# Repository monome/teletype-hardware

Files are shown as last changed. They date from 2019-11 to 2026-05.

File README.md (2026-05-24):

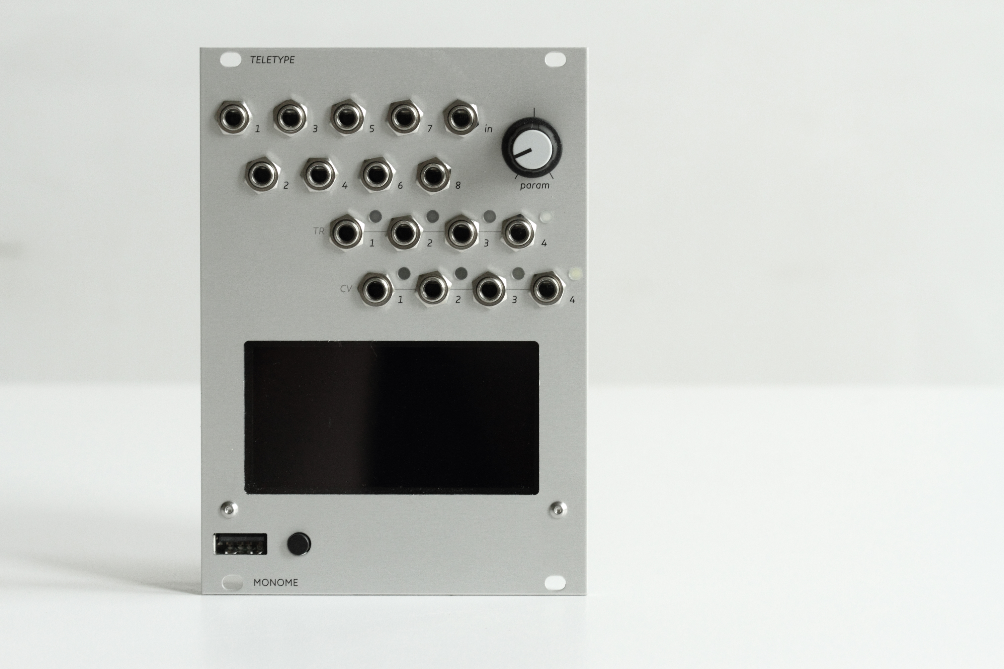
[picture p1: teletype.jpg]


# teletype hardware

eurorack module by https://monome.org

created by brian crabtree (bcrabtree@monome.org)

all circuits in eagle. can be imported to kicad.

firmware: https://github.com/monome/teletype

## BOM

- components: see ods
- octopart: https://octopart.com/bom-tool/cjqXTx5c
- mechanical (screws and spacers)
  - mcmaster: 91780A023, 91772A077, 91772A073

## license

[cc-by-sa-3.0](https://creativecommons.org/licenses/by-sa/4.0/)

commerical use: send $10 per unit produced to tehn@nnnnnnnn.co via paypal

do not use the name "monome" or "teletype" in derivative works.

## warranty and support

we can provide neither

## thank you

everyone who helped this module live

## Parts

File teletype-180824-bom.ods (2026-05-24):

250 | Qty | Value | Package | Parts | Part Number
 | --- | TOP SMD
5000 | 20 | 100n | C0402 | C1, C3, C7, C18, C21, C22, C23, C32,C26, C27, C29, C30, C31, C41, C42, C46, C47, C50, C56, C59 | CL05B104KO5NNNC
2250 | 9 | 1n | C0402 | C34, C35, C36, C37, C38, C39, C43, C57, C58 | GRM155R71H102KA01D
1000 | 4 | 2.7n | C0402 | C8, C13, C14, C15 | GRM155R71H272KA01D
500 | 2 | 22p | C0402 | C19, C20 | C0402C220J4GACTU
2250 | 9 | 33n | C0402 | C10, C12, C16, C17, C33, C45, C52, C53, C54 | CL05B333KA5NNNC
250 | 1 | 470p | C0402 | C11 | UMK105B7471KV-F
750 | 3 | 2.2u | C0603 | C9, C48, C55 | 490-10731-2-ND
500 | 2 | 4.7u | C0603 | C49, C51 | CL10A475KO8NNNC
1750 | 7 | 10u | C1206/T | C4, C6, C24, C25, C28, C44, C60 | 1276-1075-2-ND
250 | 1 | 4.7u | C1206/T | C5 | F931C475KAA
250 | 1 | 220u | C7343-43 | C2 | 478-3284-2-ND
1000 | 4 | OR | CHIP-LED0805 | LED1, LED2, LED3, LED4 | APT1608SYCK
1000 | 4 | W | CHIP-LED0805 | LED5, LED6, LED7, LED8 | LTW-C191TS5
500 | 2 | PTC-F0805-15V | F1206 | PF1, PF2 | 507-1805-2-ND
250 | 1 | 12mhz | HC49UP | Y1 | ECS-120-18-5PX-TR
250 | 1 | 47k | MNR35 | RN1 | MNR35473CT-ND
1000 | 4 | 0 | R0402 | R41, R42, R45, R48 | RC0402JR-070RL
500 | 2 | 39 | R0402 | R43, R44
4000 | 16 | 10k | R0402 | R4, R6, R7, R9, R11, R12, R13, R18, R22, R26, R28, R31, R33, R35, R39, R40 | RC0402FR-0710KL
2000 | 8 | 1k | R0402 | R3, R8, R10, R14, R17, R21, R29, R51 | 311-1.0KJRTR-ND
2000 | 8 | 20k | R0402 | R37, R38, R46, R47, R52, R53, R66, R67 | 311-20.0KLRTR-ND
500 | 2 | 2k | R0402 | R5, R16 | RC0402FR-072KL
3250 | 13 | 30k | R0402 | R15, R19, R23, R24, R25, R27, R30, R32, R34, R36, R56, R58, R60 | 311-30.0KLRTR-ND
250 | 1 | 31k6 | R0402 | R20 | YAG3115TR-ND
500 | 2 | 47k | R0402 | R1, R2 | RC0402FR-0747KL
250 | 1 | TPS2021 | SO08 | U1 | TPS2021DR
250 | 1 | TL074 | SO14 | IC1 | 296-1283-6-nd
250 | 1 | OPA4171 | SO14 | IC4 | 296-29037-1-ND
250 | 1 | ADP3339 | SOT223 | U40 | ADP3339AKCZ-3.3-R7
2500 | 10 | BAS70-04 | SOT23 | D2, D3, D4, D5, D6, D7, D8, D9, U6, U44 | BAS70-04TPMSCT-ND
250 | 1 | OKI-78SR | TO220V | IC2 | 811-2692-ND
250 | 1 | AT32UC3B064/0128/0256 | TQFP64-10X10 | U2 | AT32UC3B0512-A2UT
500 | 2 | AD5687R | TSSOP16 | U3, U4 | AD5687RBRUZ-ND
250 | 1 | AD7923 | TSSOP16 | U7 | AD7923BRUZ
 | --- | TH
250 | 1 | 10k | ALPS_POT_VERTICAL_PS | P1
250 | 1 | 1x20xFEM | 1x20 | U$1 | 1212-1105-ND
250 | 1 | USB-VERT | MOLEX-USB | USB | WM8672-ND
4250 | 17 | WQP-PJ301M-12_JACK | WQP-PJ301M-12_JACK | J1, J2, J3, J4, J5, J6, J7, J8, J9, J10, J11, J12, J13, J14, J15, J16, J17
250 | 1 |  | SWITCH-OMRON_B3F-10XX | POP | 450-1655-ND
500 | 2 |  | 2X03 | JP1, JP2 | 609-3218-ND
250 | 1 | 2510- | 2x10-SHROUDED | X1 | ED1543-ND
250 | 1 | DNP | PANASONIC-EVQ | SW40
250 | 1 | DNP | ISP-ROW | J40
250 | 1 | OLED-HEADER | 1x20xMALE |  | 1212-1149-ND

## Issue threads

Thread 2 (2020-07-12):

R22 and C22 seems to be marked switched on the pcb?

KitKatAndy, 2020-07-12:

tehn, 2020-07-15:
are you sure C22 and R22 are the correct parts you're talking about? just checked the eagle files and those parts numbers don't exist... something may be confused

tehn, 2020-07-15:
edit, just kidding, i was checking the norns shield files, ahh

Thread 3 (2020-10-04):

10k and 1k Resistors on BOM

in-fm, 2020-10-04:
The 10k and 1k resistor part numbers are switched and link to the wrong products
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

tehn, 2020-10-04:
fixed

Closed 2020-10-04.

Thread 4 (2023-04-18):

Add gerbers to repository

drbloop, 2023-04-18:
I would like to fabricate some PCBs but I haven't been able to get Eagle to work properly on my machine to convert the PCB `.brd` file to gerber files that are required for PCB fab services. Is it possible to do this conversion on your end and upload the gerber zip files to this repository? I think this will help others out too, by removing the need to do a conversion step.

Example from a Teletype expansion board - https://github.com/bpcmusic/telex/tree/master/hardware/TELEXi/board/gerbers

tehn, 2023-04-18:
We've posted these files for educational purposes, not as an online store.

Closed 2023-04-18.

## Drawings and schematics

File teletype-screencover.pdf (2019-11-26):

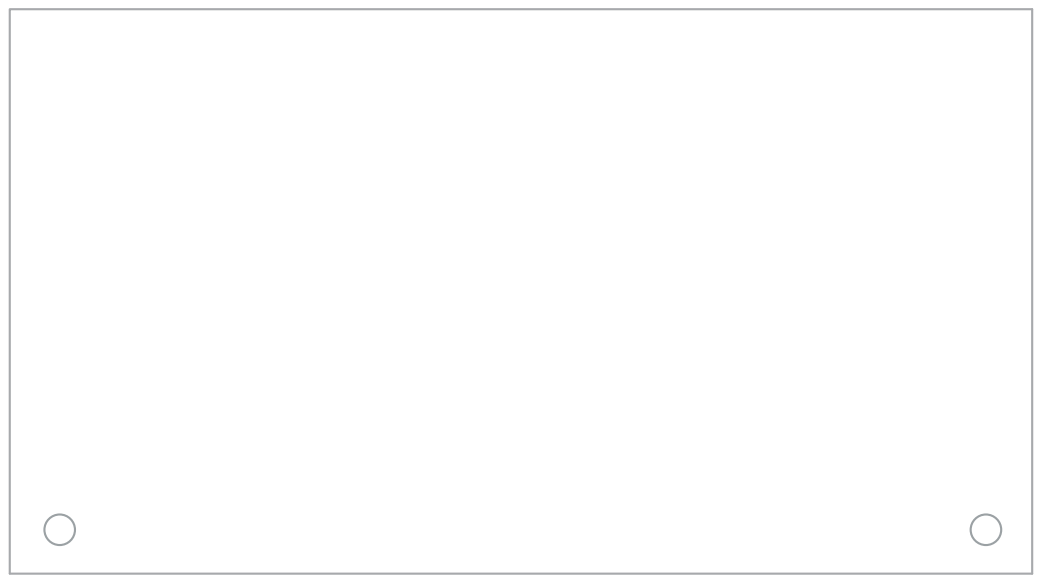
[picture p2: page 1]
TELETYPE; MONOME; param

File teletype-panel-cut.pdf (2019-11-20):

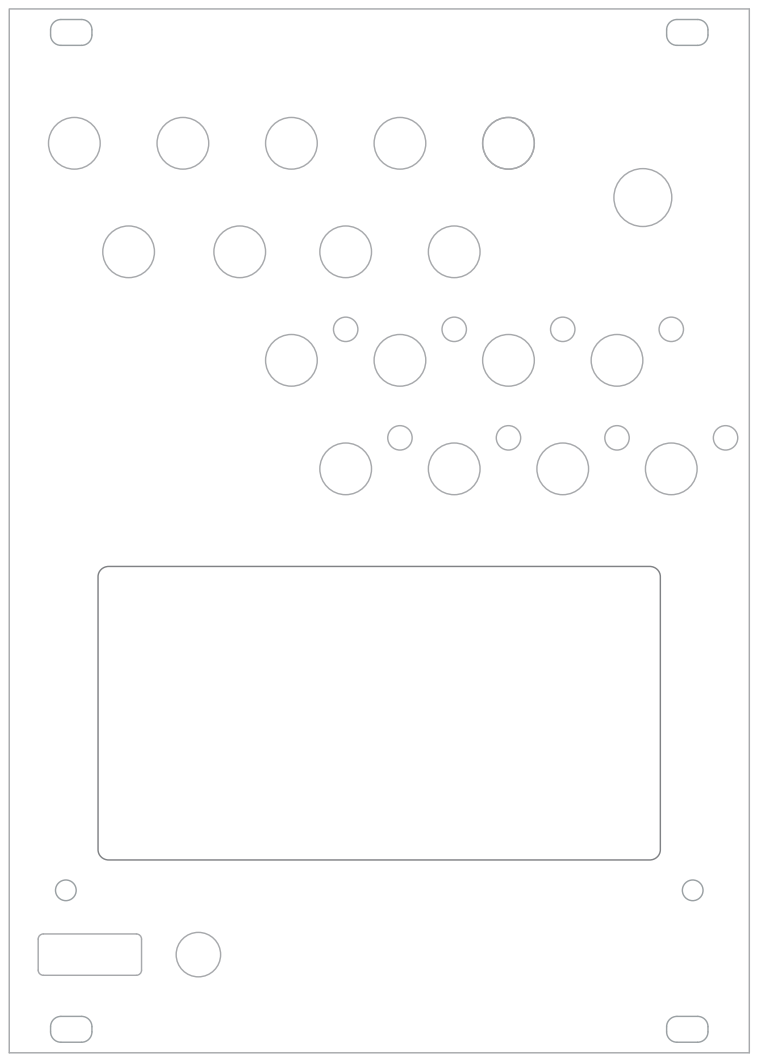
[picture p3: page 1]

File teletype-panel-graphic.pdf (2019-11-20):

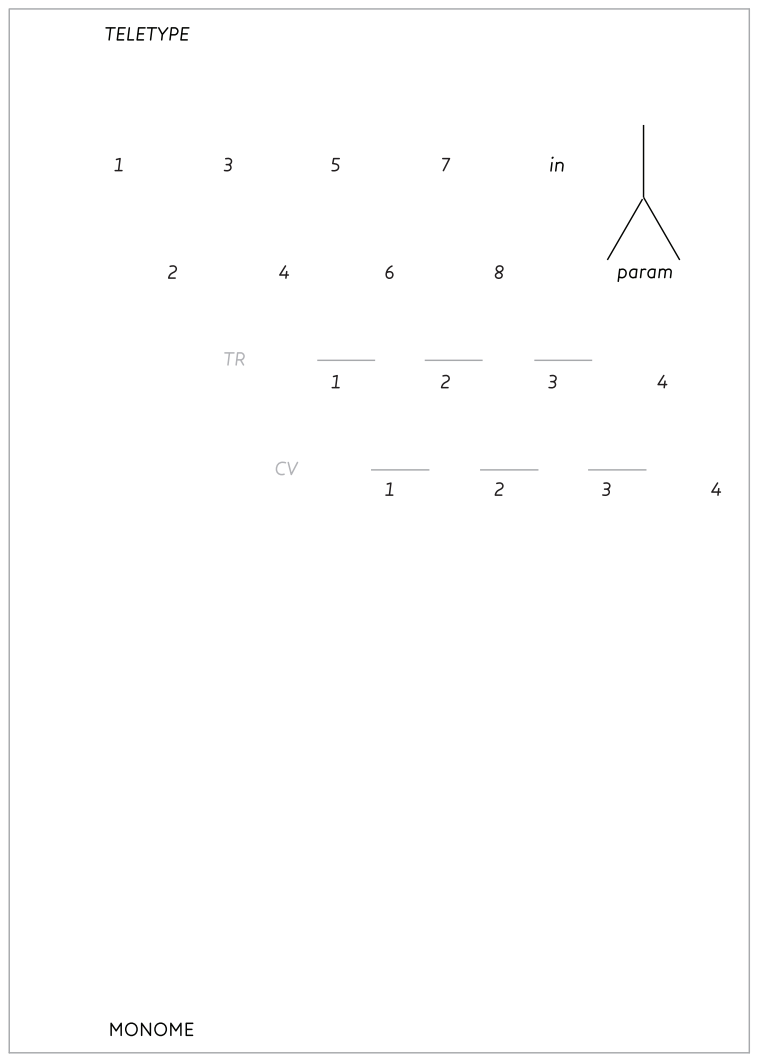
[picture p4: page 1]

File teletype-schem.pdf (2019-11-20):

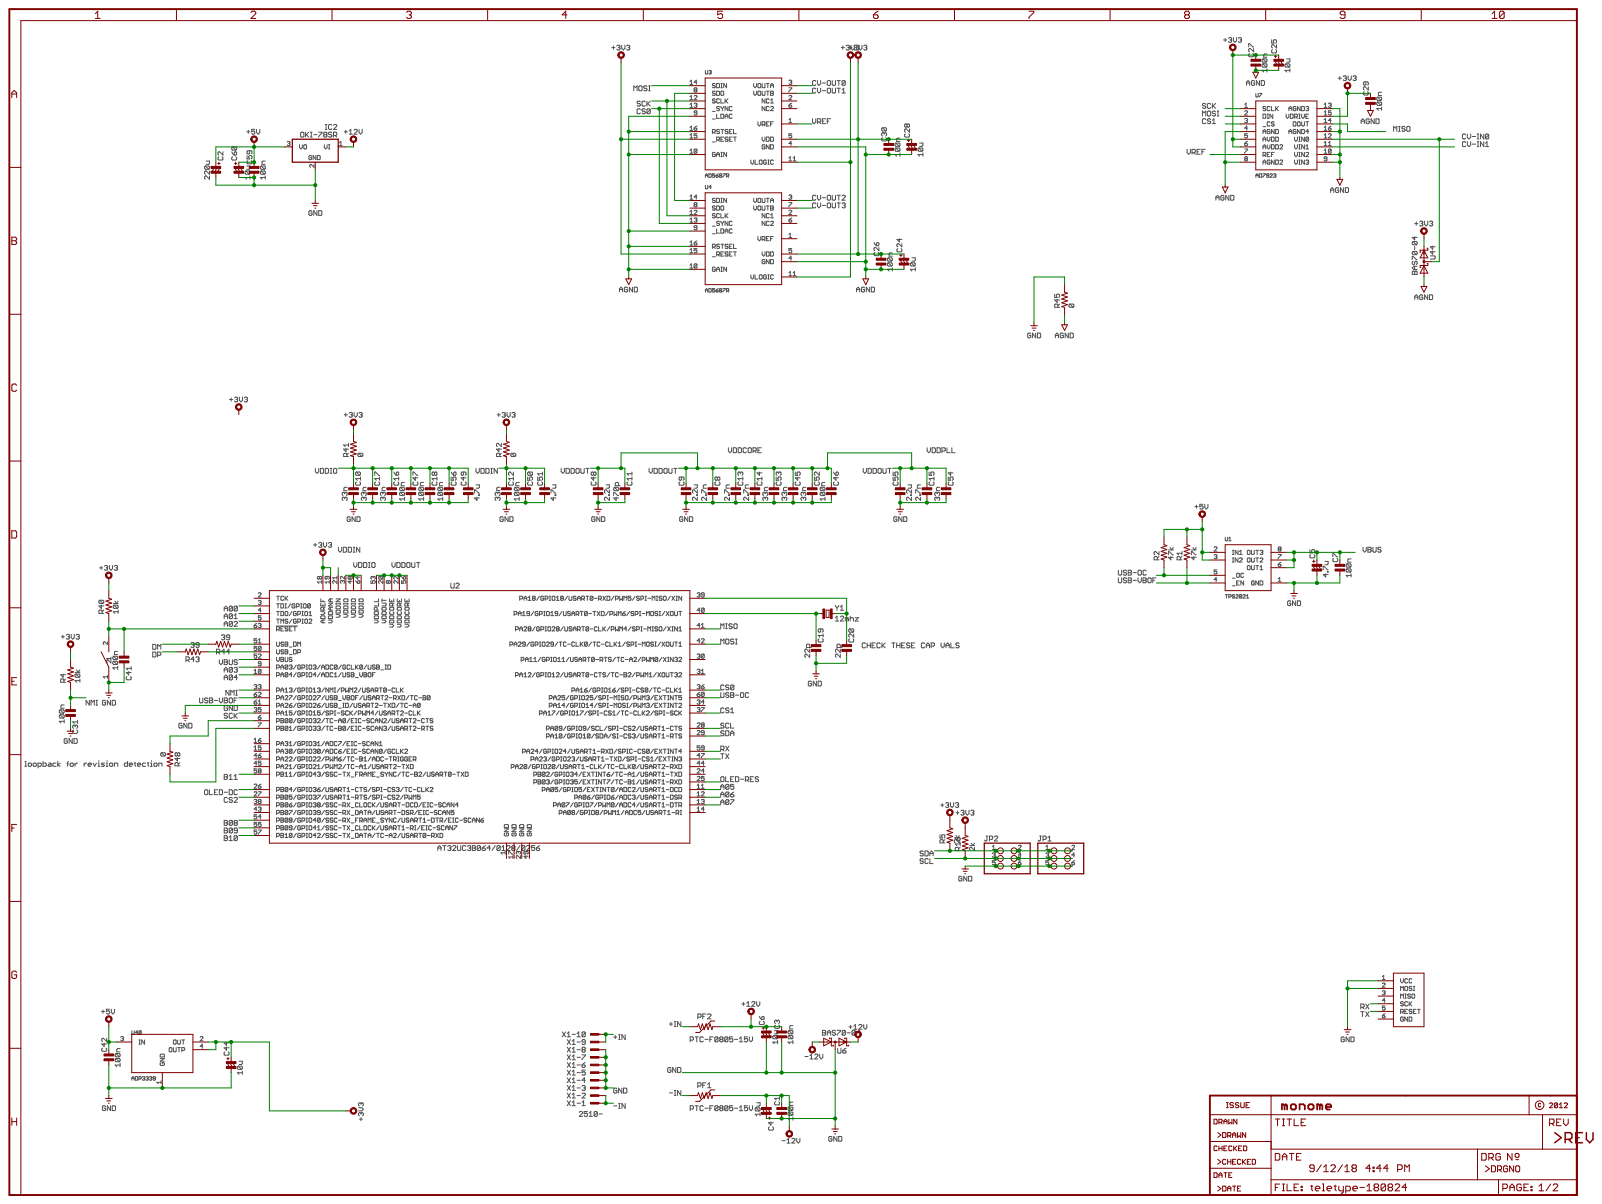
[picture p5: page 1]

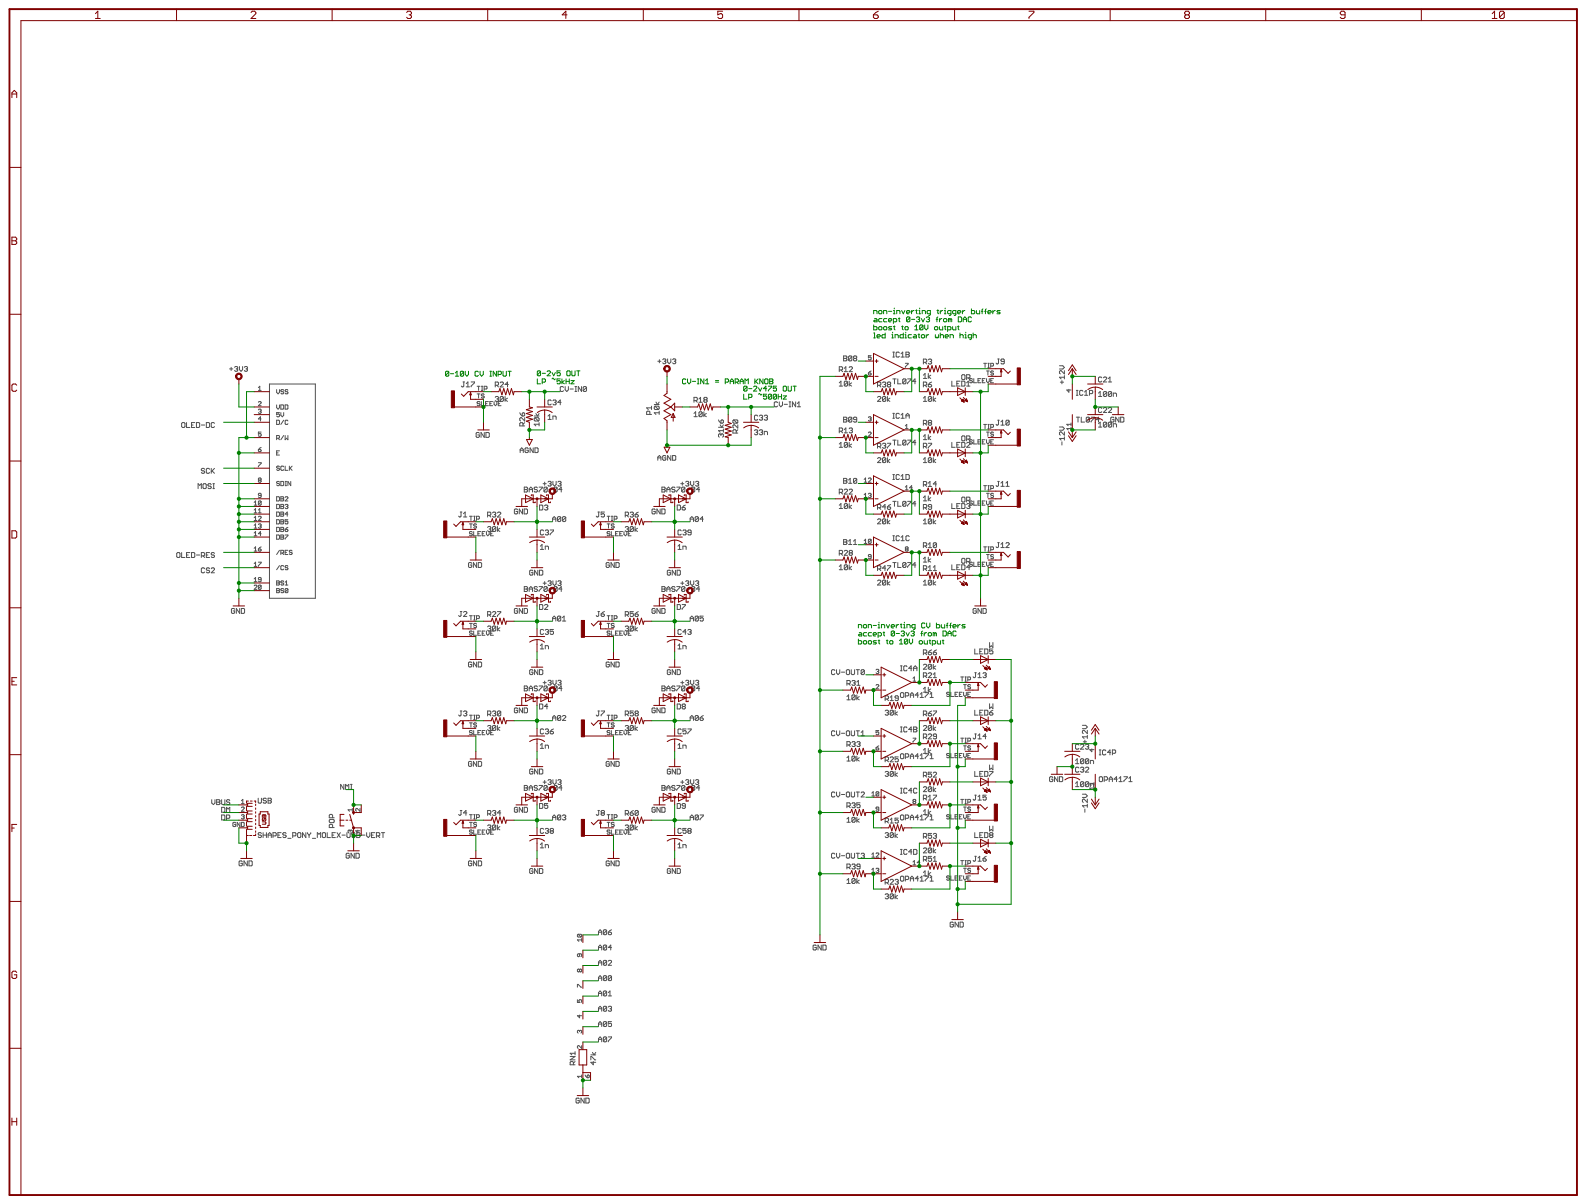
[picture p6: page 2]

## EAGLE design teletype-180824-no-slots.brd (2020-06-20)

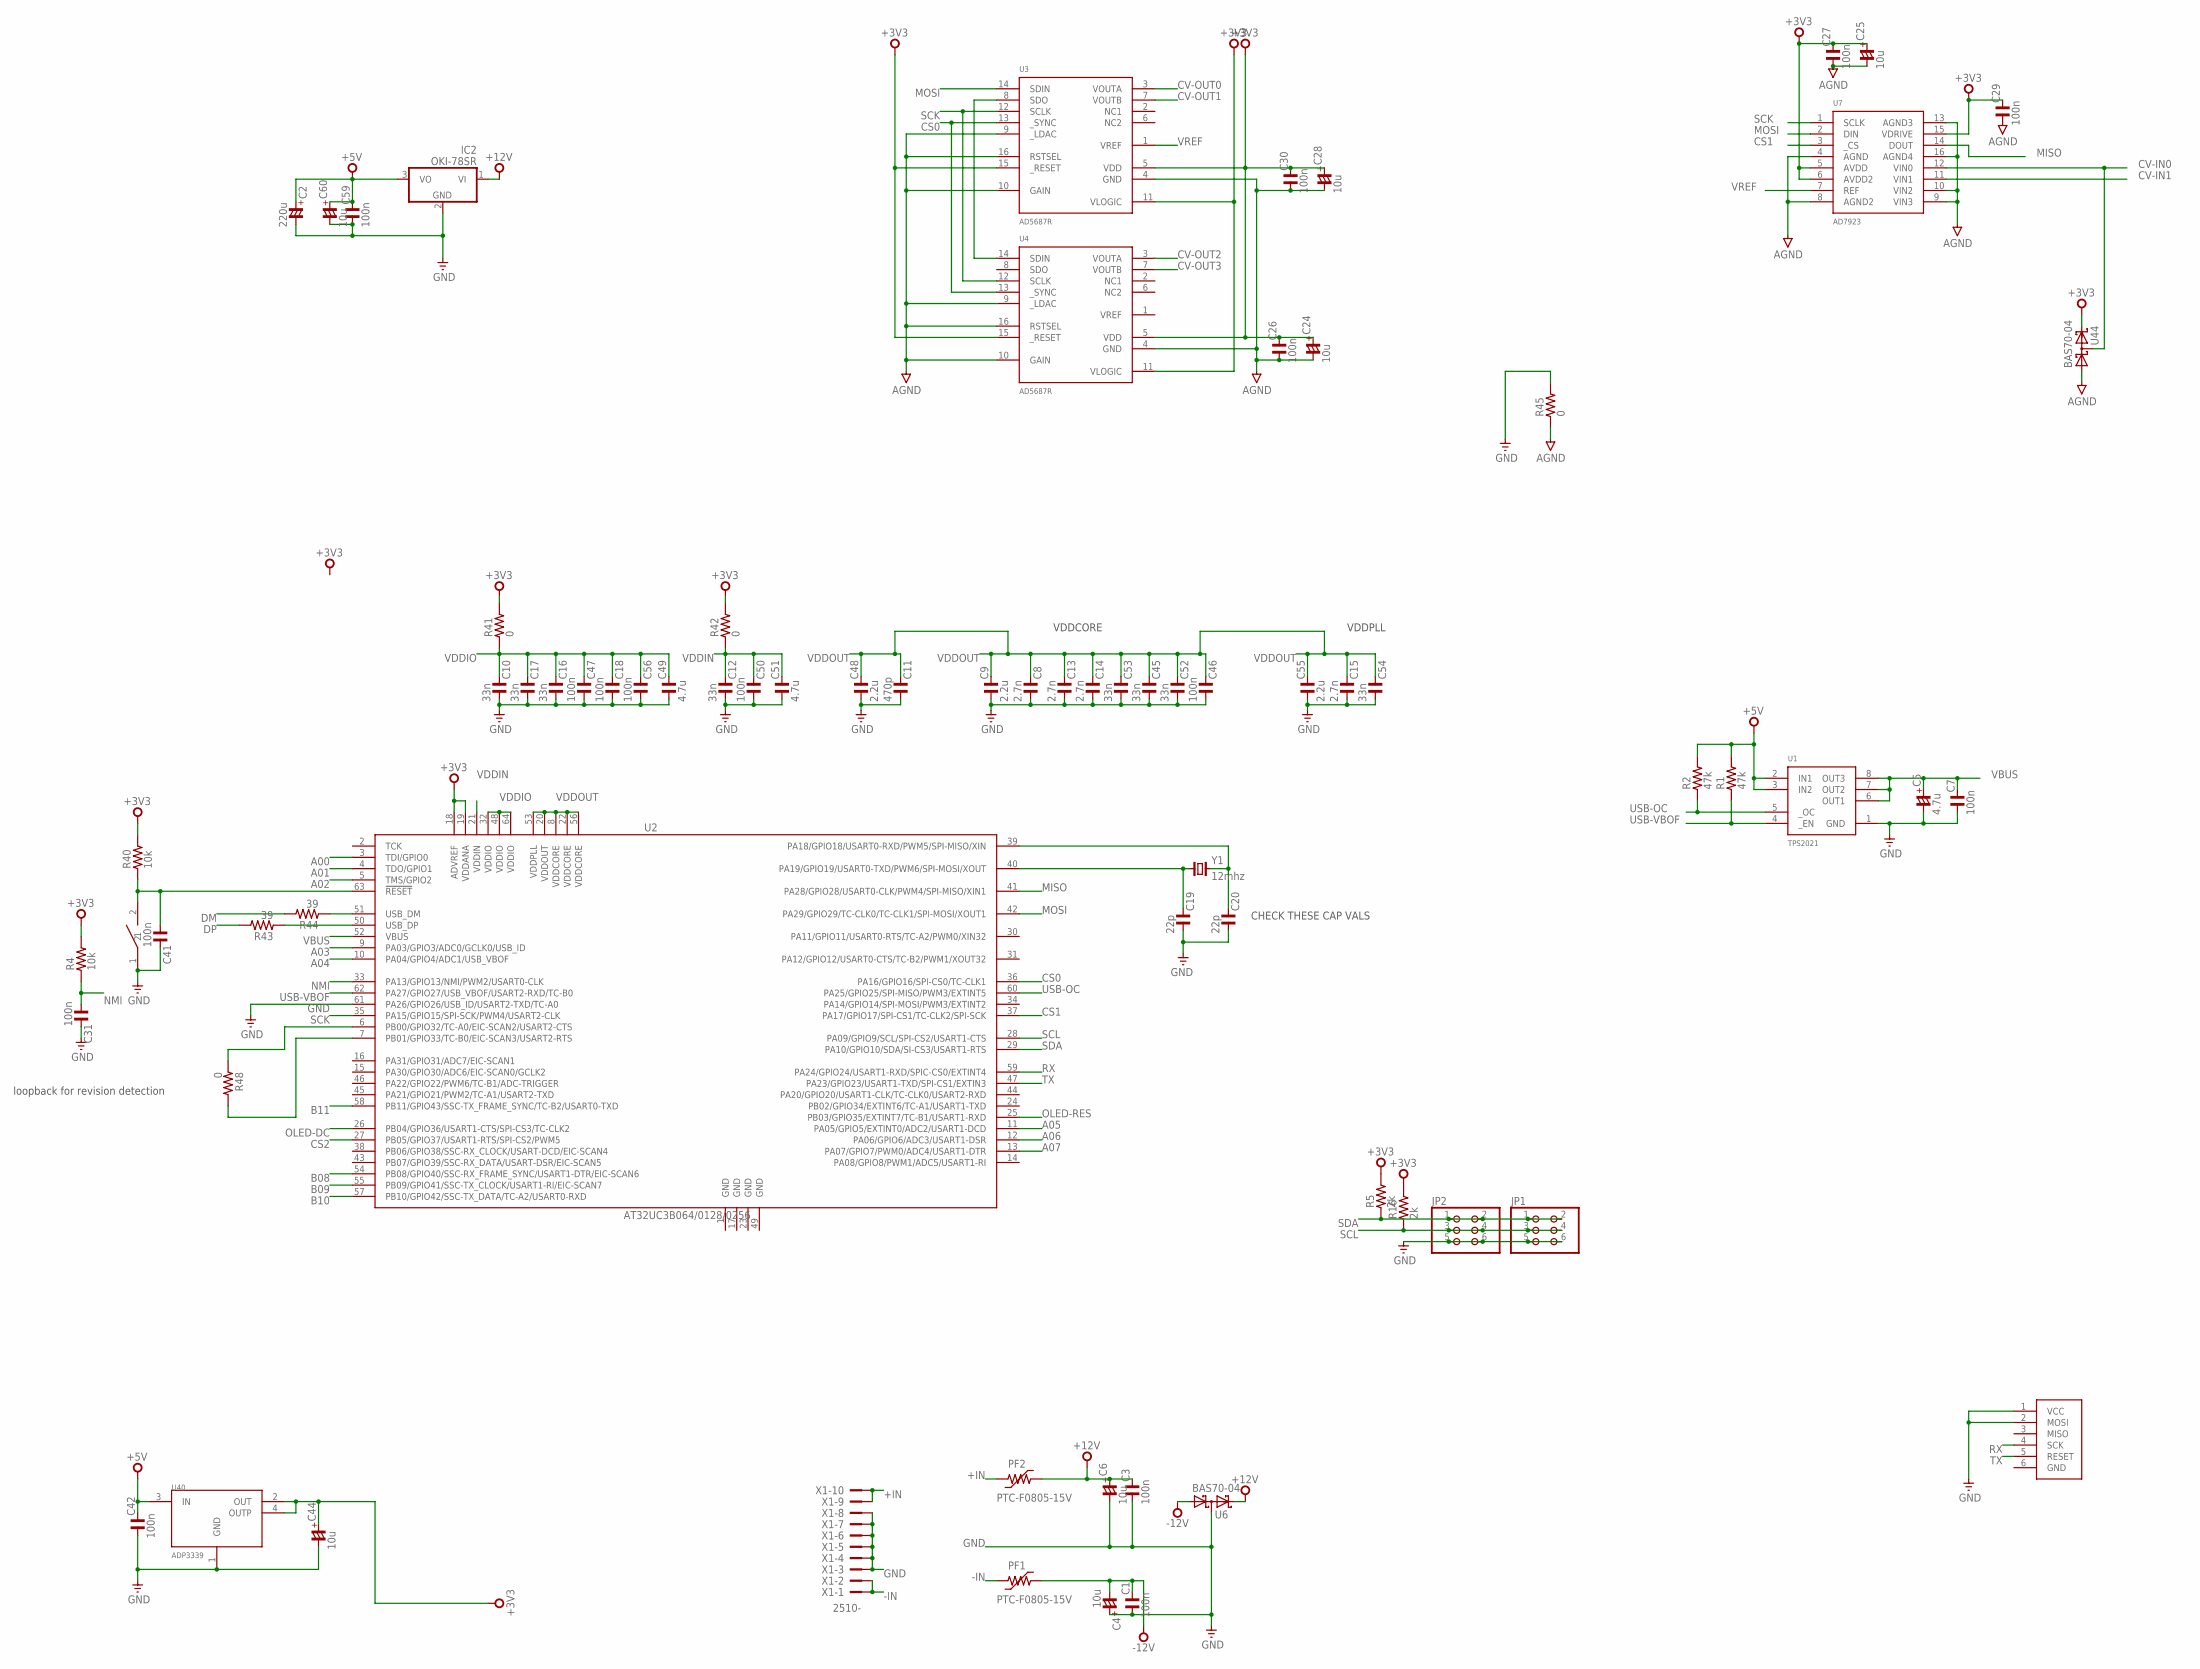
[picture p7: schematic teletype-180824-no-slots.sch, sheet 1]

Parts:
C1, C3, C7, C18, C26, C27, C29, C30, C31, C41, C42, C46, C47, C50, C56, C59: 100n; C0402
C2: 220u; C7343-43
C4, C6, C24, C25, C28, C44, C60: 10u; C1206/T
C5: 4.7u; C1206/T
C8, C13, C14, C15: 2.7n; C0402
C9, C48, C55: 2.2u; C0603
C10, C12, C16, C17, C45, C52, C53, C54: 33n; C0402
C11: 470p; C0402
C19, C20: 22p; C0402
C49, C51: 4.7u; C0603
IC2: OKI-78SR; TO220V
J40: ISP-ROW
JP1, JP2: PINHD-2X3; 2X03
PF1, PF2: PTC-F0805-15V; F1206
R1, R2: 47k; R0402
R4, R40: 10k; R0402
R5, R16: 2k; R0402
R41, R42, R48: 0; R0402
R43, R44: 39; R0402
R45: 0; R0603
SW40: PANASONIC-EVQ
U1: TPS2021; SO08
U2: AT32UC3B064/0128/0256; TQFP64-10X10
U3, U4: AD5687R; TSSOP16
U6, U44: BAS70-04; SOT23
U7: AD7923; TSSOP16
U40: ADP3339; SOT223
X1: 2510-; PAK100/2500-10
Y1: 12mhz; HC49UP

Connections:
+3V3: C24.+, C25.+, C26.2, C27.2, C28.+, C29.2, C30.2, C44.+, R4.2, R5.2, R16.2, R40.2, R41.2, R42.2, U2.18 (ADVREF), U2.19 (VDDANA), U3.5 (VDD), U3.11 (VLOGIC), U3.15 (_RESET), U4.5 (VDD), U4.11 (VLOGIC), U4.15 (_RESET), U7.5 (AVDD), U7.6 (AVDD2), U7.15 (VDRIVE), U40.2 (OUT), U40.4 (OUTP), U44.2 (C2); also elsewhere on the board
+5V: C2.+, C42.2, C59.2, C60.+, IC2.3 (VO), R1.2, R2.2, U1.2 (IN1), U1.3 (IN2), U40.3 (IN)
+12V: C3.2, C6.+, IC2.1 (VI), PF2.2, U6.2 (C2); also elsewhere on the board
+IN: PF2.1, X1.9, X1.10
-12V: C1.2, C4.-, PF1.2, U6.1 (A1); also elsewhere on the board
-IN: PF1.1, X1.1, X1.2
A00: U2.3 (TDI/GPIO0); also elsewhere on the board
A01: U2.4 (TDO/GPIO1); also elsewhere on the board
A02: U2.5 (TMS/GPIO2); also elsewhere on the board
A03: U2.9 (PA03/GPIO3/ADC0/GCLK0/USB_ID); also elsewhere on the board
A04: U2.10 (PA04/GPIO4/ADC1/USB_VBOF); also elsewhere on the board
A05: U2.11 (PA05/GPIO5/EXTINT0/ADC2/USART1-DCD); also elsewhere on the board
A06: U2.12 (PA06/GPIO6/ADC3/USART1-DSR); also elsewhere on the board
A07: U2.13 (PA07/GPIO7/PWM0/ADC4/USART1-DTR); also elsewhere on the board
AGND: C24.-, C25.-, C26.1, C27.1, C28.-, C29.1, C30.1, R45.1, U3.4 (GND), U3.9 (_LDAC), U3.10 (GAIN), U3.16 (RSTSEL), U4.4 (GND), U4.9 (_LDAC), U4.10 (GAIN), U4.16 (RSTSEL), U7.4 (AGND), U7.8 (AGND2), U7.9 (VIN3), U7.10 (VIN2), U7.13 (AGND3), U7.16 (AGND4), U44.1 (A1); also elsewhere on the board
B08: U2.54 (PB08/GPIO40/SSC-RX_FRAME_SYNC/USART1-DT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); also elsewhere on the board
B09: U2.55 (PB09/GPIO41/SSC-TX_CLOCK/USART1-RI/EIC-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); also elsewhere on the board
B10: U2.57 (PB10/GPIO42/SSC-TX_DATA/TC-A2/USART0-RXD); also elsewhere on the board
B11: U2.58 (PB11/GPIO43/SSC-TX_FRAME_SYNC/TC-B2/USA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); also elsewhere on the board
CS0: U2.36 (PA16/GPIO16/SPI-CS0/TC-CLK1), U3.13 (_SYNC), U4.13 (_SYNC)
CS1: U2.37 (PA17/GPIO17/SPI-CS1/TC-CLK2/SPI-SCK), U7.3 (_CS)
CS2: U2.27 (PB05/GPIO37/USART1-RTS/SPI-CS2/PWM5); also elsewhere on the board
CV-IN0: U7.12 (VIN0), U44.3 (C1A2); also elsewhere on the board
CV-IN1: U7.11 (VIN1); also elsewhere on the board
CV-OUT0: U3.3 (VOUTA); also elsewhere on the board
CV-OUT1: U3.7 (VOUTB); also elsewhere on the board
CV-OUT2: U4.3 (VOUTA); also elsewhere on the board
CV-OUT3: U4.7 (VOUTB); also elsewhere on the board
DM: R44.2; also elsewhere on the board
DP: R43.2; also elsewhere on the board
GND: C1.1, C2.-, C3.1, C4.+, C5.-, C6.-, C7.1, C8.1, C9.1, C10.1, C11.1, C12.1, C13.1, C14.1, C15.1, C16.1, C17.1, C18.1, C19.1, C20.1, C31.2, C41.2, C42.1, C44.-, C45.1, C46.1, C47.1, C48.1, C49.1, C50.1, C51.1, C52.1, C53.1, C54.1, C55.1, C56.1, C59.1, C60.-, IC2.2 (GND), J40.1 (VCC), J40.2 (MOSI), JP1.5, JP1.6, JP2.5, JP2.6, R45.2, SW40.1, U1.1 (GND), U2.1 (GND), U2.17 (GND), U2.23 (GND), U2.49 (GND), U2.61 (PA26/GPIO26/USB_ID/USART2-TXD/TC-A0), U6.3 (C1A2), U40.1 (GND), X1.3, X1.4, X1.5, X1.6, X1.7, X1.8; also elsewhere on the board
MISO: U2.41 (PA28/GPIO28/USART0-CLK/PWM4/SPI-MISO/XI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), U7.14 (DOUT)
MOSI: U2.42 (PA29/GPIO29/TC-CLK0/TC-CLK1/SPI-MOSI/XO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), U3.14 (SDIN), U7.2 (DIN); also elsewhere on the board
unnamed: R44.1, U2.51 (USB_DM)
unnamed: R43.1, U2.50 (USB_DP)
unnamed: U3.8 (SDO), U4.14 (SDIN)
unnamed: C20.2, U2.39 (PA18/GPIO18/USART0-RXD/PWM5/SPI-MISO/XIN), Y1.2
unnamed: R48.1, U2.6 (PB00/GPIO32/TC-A0/EIC-SCAN2/USART2-CTS)
unnamed: R48.2, U2.7 (PB01/GPIO33/TC-B0/EIC-SCAN3/USART2-RTS)
unnamed: C19.2, U2.40 (PA19/GPIO19/USART0-TXD/PWM6/SPI-MOSI/XO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), Y1.1
NMI: C31.1, R4.1, U2.33 (PA13/GPIO13/NMI/PWM2/USART0-CLK); also elsewhere on the board
OLED-DC: U2.26 (PB04/GPIO36/USART1-CTS/SPI-CS3/TC-CLK2); also elsewhere on the board
OLED-RES: U2.25 (PB03/GPIO35/EXTINT7/TC-B1/USART1-RXD); also elsewhere on the board
RESET: C41.1, R40.1, SW40.2, U2.63 (!RESET)
RX: J40.4 (SCK), U2.59 (PA24/GPIO24/USART1-RXD/SPIC-CS0/EXTINT4)
SCK: U2.35 (PA15/GPIO15/SPI-SCK/PWM4/USART2-CLK), U3.12 (SCLK), U4.12 (SCLK), U7.1 (SCLK); also elsewhere on the board
SCL: JP1.3, JP1.4, JP2.3, JP2.4, R16.1, U2.28 (PA09/GPIO9/SCL/SPI-CS2/USART1-CTS)
SDA: JP1.1, JP1.2, JP2.1, JP2.2, R5.1, U2.29 (PA10/GPIO10/SDA/SI-CS3/USART1-RTS)
TX: J40.5 (RESET), U2.47 (PA23/GPIO23/USART1-TXD/SPI-CS1/EXTIN3)
USB-OC: R2.1, U1.5 (_OC), U2.60 (PA25/GPIO25/SPI-MISO/PWM3/EXTINT5)
USB-VBOF: R1.1, U1.4 (_EN), U2.62 (PA27/GPIO27/USB_VBOF/USART2-RXD/TC-B0)
VBUS: C5.+, C7.2, U1.6 (OUT1), U1.7 (OUT2), U1.8 (OUT3), U2.52 (VBUS); also elsewhere on the board
VDDIN: C12.2, C50.2, C51.2, R42.1, U2.21 (VDDIN)
VDDIO: C10.2, C16.2, C17.2, C18.2, C47.2, C49.2, C56.2, R41.1, U2.32 (VDDIO), U2.48 (VDDIO), U2.64 (VDDIO)
VDDOUT: C8.2, C9.2, C11.2, C13.2, C14.2, C15.2, C45.2, C46.2, C48.2, C52.2, C53.2, C54.2, C55.2, U2.8 (VDDCORE), U2.20 (VDDOUT), U2.22 (VDDCORE), U2.53 (VDDPLL), U2.56 (VDDCORE)
VREF: U3.1 (VREF), U7.7 (REF)

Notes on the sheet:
CHECK THESE CAP VALS
VDDCORE
VDDPLL
loopback for revision detection

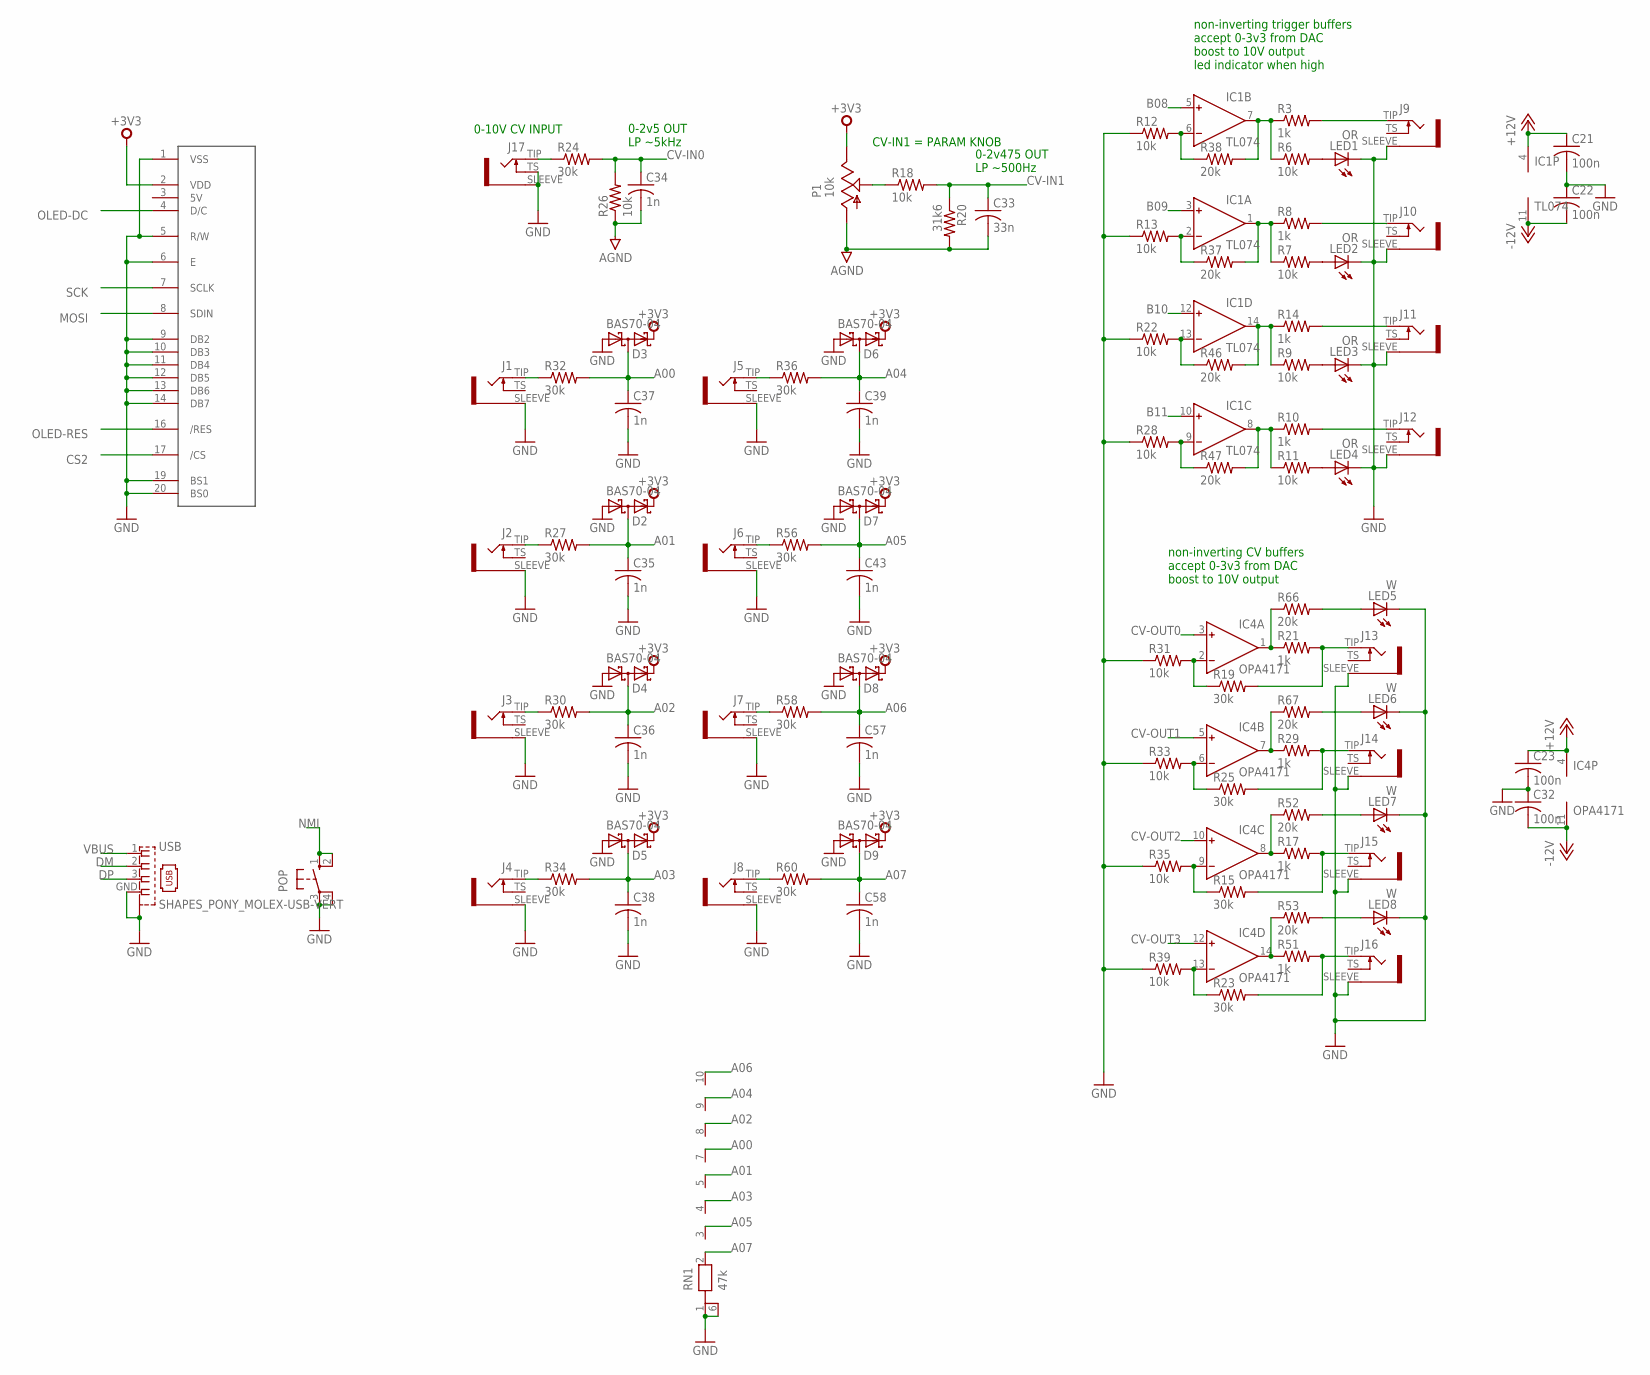
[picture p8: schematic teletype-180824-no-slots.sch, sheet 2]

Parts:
C21, C22, C23, C32: 100n; C0402
C33: 33n; C0402
C34, C35, C36, C37, C38, C39, C43, C57, C58: 1n; C0402
D2, D3, D4, D5, D6, D7, D8, D9: BAS70-04; SOT23
IC1: TL074; SO14
IC4: OPA4171; SO14; MPN AD8644ARZ
J1, J2, J3, J4, J5, J6, J7, J8, J9, J10, J11, J12, J13, J14, J15, J16, J17: WQP-PJ301M-12_JACK
LED1, LED2, LED3, LED4: OR; CHIP-LED0805
LED5, LED6, LED7, LED8: W; CHIP-LED0805
P1: 10k; ALPS_POT_VERTICAL
POP: SWITCH-OMRON_10-XX; SWITCH-OMRON_B3F-10XX
R3, R8, R10, R14, R17, R21, R29, R51: 1k; R0402
R6, R7, R9, R11, R12, R13, R18, R22, R26, R28, R31, R33, R35, R39: 10k; R0402
R15, R19, R23, R24, R25, R27, R30, R32, R34, R36, R56, R58, R60: 30k; R0402
R20: 31k6; R0402
R37, R38, R46, R47, R52, R53, R66, R67: 20k; R0402
RN1: 47k; MNR35
U$1: OLED128X64; OLED-ALEPH
USB: SHAPES_PONY_MOLEX-USB-VERT; SHAPES_PONY_MOLEX-USB

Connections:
+3V3: D2.2 (C2), D3.2 (C2), D4.2 (C2), D5.2 (C2), D6.2 (C2), D7.2 (C2), D8.2 (C2), D9.2 (C2), P1.P$1 (E), U$1.2 (VDD); also elsewhere on the board
+12V: C21.1, C23.1, IC1.4 (V+), IC4.4 (V+); also elsewhere on the board
-12V: C22.2, C32.2, IC1.11 (V-), IC4.11 (V-); also elsewhere on the board
A00: C37.1, D3.3 (C1A2), R32.2, RN1.7 (6); also elsewhere on the board
A01: C35.1, D2.3 (C1A2), R27.2, RN1.5; also elsewhere on the board
A02: C36.1, D4.3 (C1A2), R30.2, RN1.8 (7); also elsewhere on the board
A03: C38.1, D5.3 (C1A2), R34.2, RN1.4; also elsewhere on the board
A04: C39.1, D6.3 (C1A2), R36.2, RN1.9 (8); also elsewhere on the board
A05: C43.1, D7.3 (C1A2), R56.2, RN1.3; also elsewhere on the board
A06: C57.1, D8.3 (C1A2), R58.2, RN1.10 (9); also elsewhere on the board
A07: C58.1, D9.3 (C1A2), R60.2, RN1.2; also elsewhere on the board
AGND: C33.2, C34.2, P1.P$3 (A), R20.2, R26.1; also elsewhere on the board
B08: IC1.5 (IN+); also elsewhere on the board
B09: IC1.3 (IN+); also elsewhere on the board
B10: IC1.12 (IN+); also elsewhere on the board
B11: IC1.10 (IN+); also elsewhere on the board
CS2: U$1.17 (/CS); also elsewhere on the board
CV-IN0: C34.1, R24.2, R26.2; also elsewhere on the board
CV-IN1: C33.1, R18.2, R20.1; also elsewhere on the board
CV-OUT0: IC4.3 (IN+); also elsewhere on the board
CV-OUT1: IC4.5 (IN+); also elsewhere on the board
CV-OUT2: IC4.10 (IN+); also elsewhere on the board
CV-OUT3: IC4.12 (IN+); also elsewhere on the board
DM: USB.2; also elsewhere on the board
DP: USB.3; also elsewhere on the board
GND: C21.2, C22.1, C23.2, C32.1, C35.2, C36.2, C37.2, C38.2, C39.2, C43.2, C57.2, C58.2, D2.1 (A1), D3.1 (A1), D4.1 (A1), D5.1 (A1), D6.1 (A1), D7.1 (A1), D8.1 (A1), D9.1 (A1), J1.SLEEVE, J2.SLEEVE, J3.SLEEVE, J4.SLEEVE, J5.SLEEVE, J6.SLEEVE, J7.SLEEVE, J8.SLEEVE, J9.SLEEVE, J10.SLEEVE, J11.SLEEVE, J12.SLEEVE, J13.SLEEVE, J14.SLEEVE, J15.SLEEVE, J16.SLEEVE, J17.SLEEVE, J17.TS, LED1.C, LED2.C, LED3.C, LED4.C, LED5.C, LED6.C, LED7.C, LED8.C, POP.3, POP.4 (P1), R12.1, R13.1, R22.1, R28.1, R31.1, R33.1, R35.1, R39.1, RN1.1, RN1.6 (10), U$1.1 (VSS), U$1.5 (R/W), U$1.6 (E), U$1.9 (DB2), U$1.10 (DB3), U$1.11 (DB4), U$1.12 (DB5), U$1.13 (DB6), U$1.14 (DB7), U$1.19 (BS1), U$1.20 (BS0), USB.GND, USB.M1 (S1), USB.M2 (S1), USB.M4 (S1); also elsewhere on the board
MOSI: U$1.8 (SDIN); also elsewhere on the board
unnamed: IC1.7 (OUT), R3.1, R6.1, R38.2
unnamed: IC1.1 (OUT), R7.1, R8.1, R37.2
unnamed: IC1.14 (OUT), R9.1, R14.1, R46.2
unnamed: IC1.8 (OUT), R10.1, R11.1, R47.2
unnamed: J9.TIP, R3.2
unnamed: J10.TIP, R8.2
unnamed: J11.TIP, R14.2
unnamed: J12.TIP, R10.2
unnamed: P1.P$2 (S), R18.1
unnamed: IC4.1 (OUT), R21.1, R66.1
unnamed: IC4.7 (OUT), R29.1, R67.1
unnamed: LED5.A, R66.2
unnamed: J15.TIP, R15.2, R17.2
unnamed: J16.TIP, R23.2, R51.2
unnamed: IC4.8 (OUT), R17.1, R52.1
unnamed: LED6.A, R67.2
unnamed: IC4.14 (OUT), R51.1, R53.1
unnamed: LED7.A, R52.2
unnamed: LED8.A, R53.2
unnamed: J13.TIP, R19.2, R21.2
unnamed: J17.TIP, R24.1
unnamed: J14.TIP, R25.2, R29.2
unnamed: J2.TIP, R27.1
unnamed: J3.TIP, R30.1
unnamed: J4.TIP, R34.1
unnamed: J1.TIP, R32.1
unnamed: J5.TIP, R36.1
unnamed: J6.TIP, R56.1
unnamed: J7.TIP, R58.1
unnamed: J8.TIP, R60.1
unnamed: LED1.A, R6.2
unnamed: LED2.A, R7.2
unnamed: LED3.A, R9.2
unnamed: LED4.A, R11.2
NMI: POP.1 (S), POP.2 (S1); also elsewhere on the board
OLED-DC: U$1.4 (D/C); also elsewhere on the board
OLED-RES: U$1.16 (/RES); also elsewhere on the board
RG1: IC1.6 (IN-), R12.2, R38.1
RG2: IC1.2 (IN-), R13.2, R37.1
RG3: IC1.13 (IN-), R22.2, R46.1
RG4: IC1.9 (IN-), R28.2, R47.1
RG5: IC4.2 (IN-), R19.1, R31.2
RG6: IC4.6 (IN-), R25.1, R33.2
RG7: IC4.9 (IN-), R15.1, R35.2
RG8: IC4.13 (IN-), R23.1, R39.2
SCK: U$1.7 (SCLK); also elsewhere on the board
VBUS: USB.1; also elsewhere on the board

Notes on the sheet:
non-inverting CV buffers accept 0-3v3 from DAC boost to 10V output
non-inverting trigger buffers accept 0-3v3 from DAC boost to 10V output led indicator when high
CV-IN1 = PARAM KNOB
0-10V CV INPUT
0-2v5 OUT LP ~5kHz
0-2v475 OUT LP ~500Hz

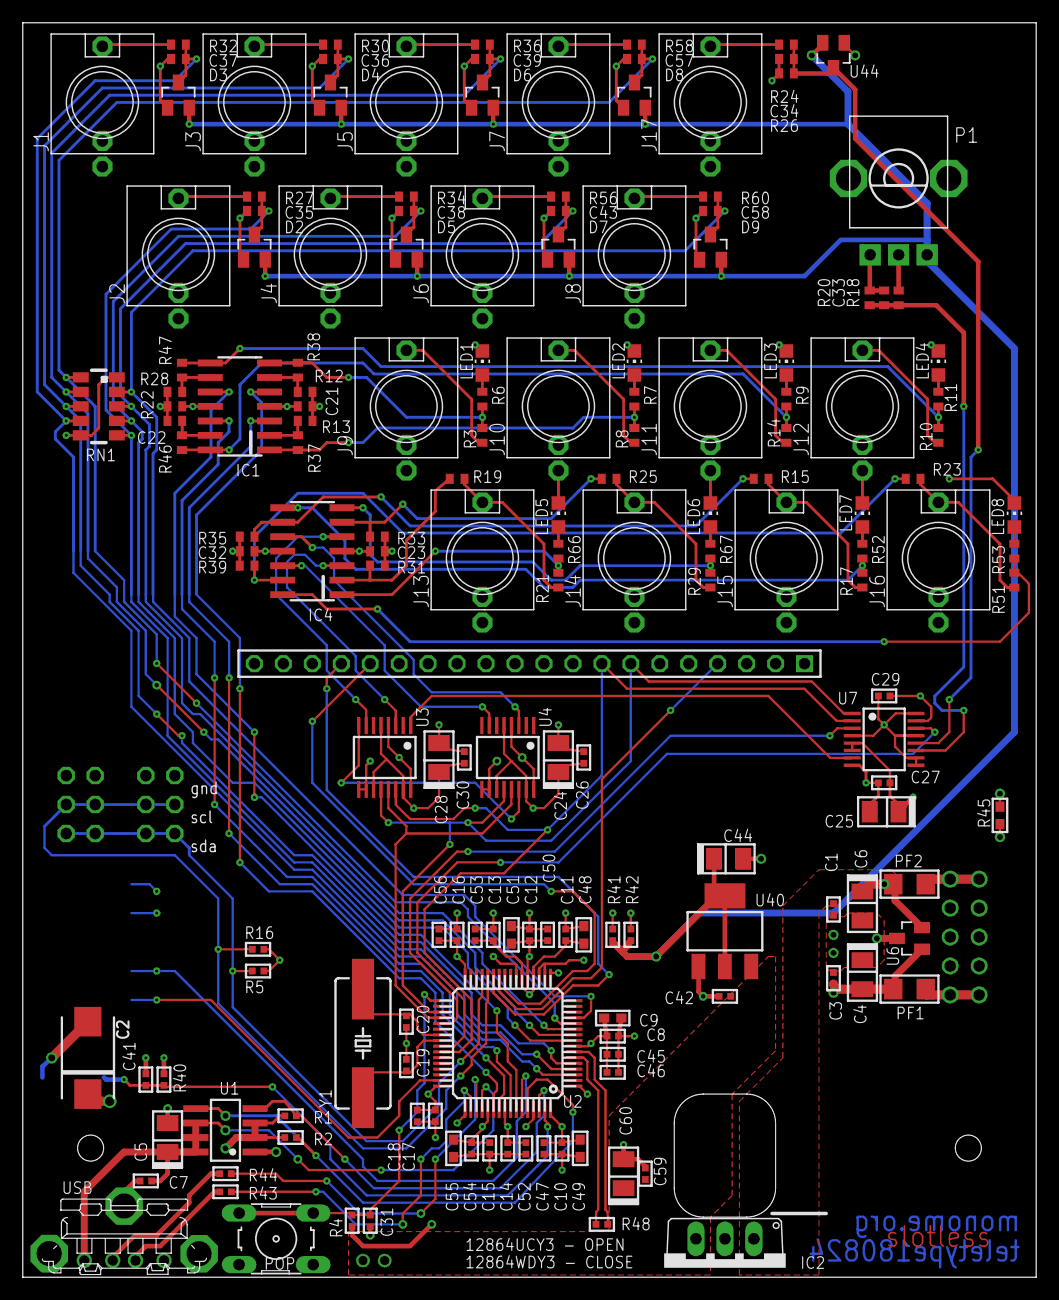
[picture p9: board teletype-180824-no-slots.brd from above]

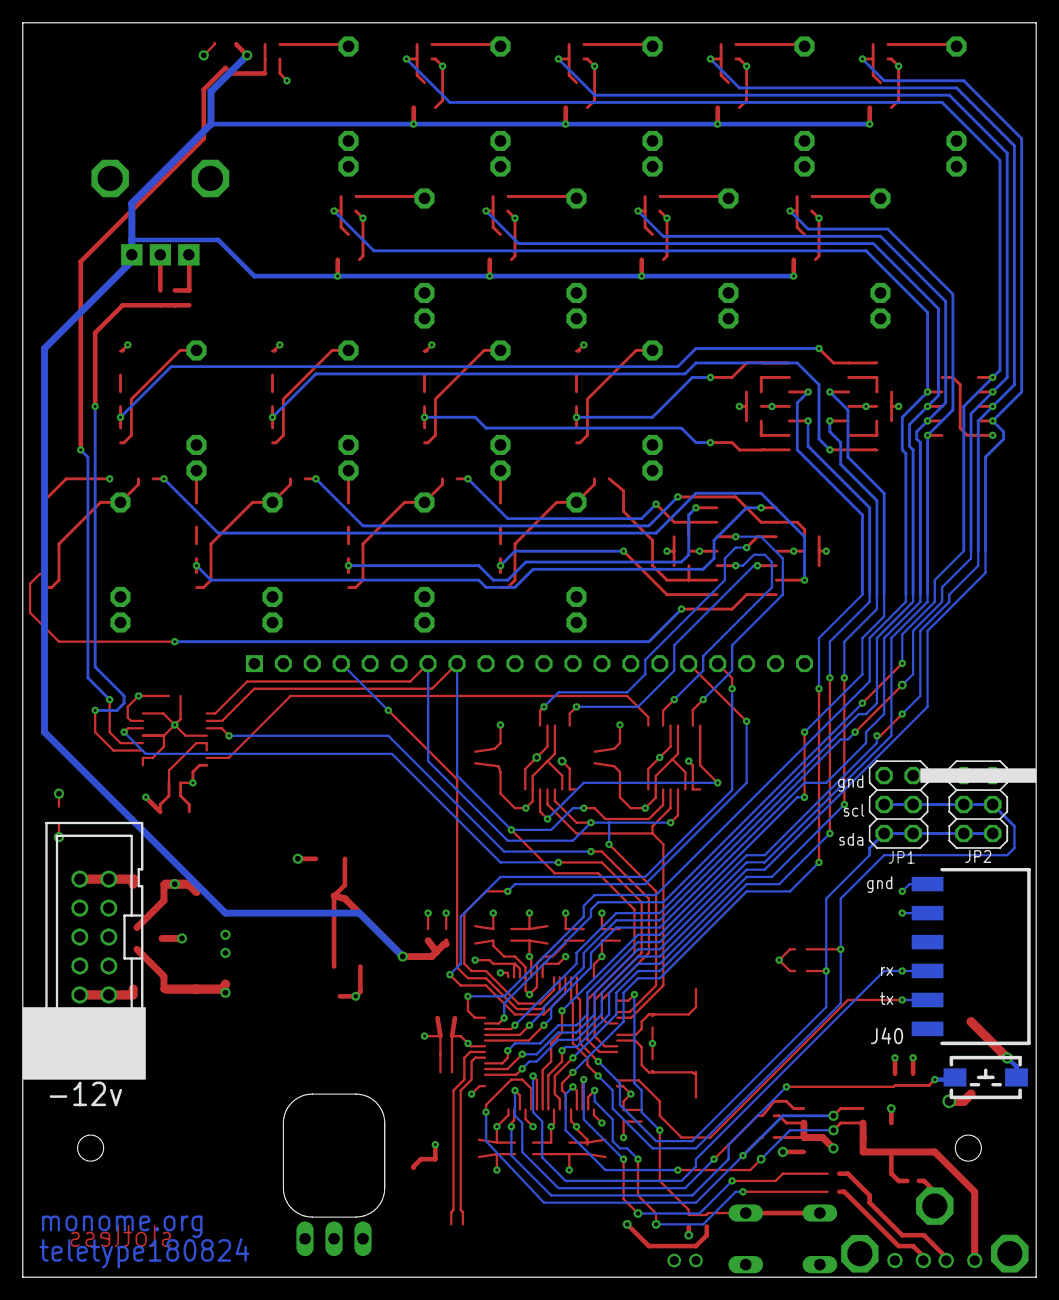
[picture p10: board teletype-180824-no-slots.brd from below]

Board: 4 copper layers, 88.9 x 110.0 mm, 172 parts (5 on the bottom side), 98 nets.

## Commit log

2019-11-20 bom link
2020-06-20 An alternative version with all slots from the board (this may be easier for some fab houses to manufacture) (#1)
    [teletype-180824-no-slots.brd, teletype-180824-no-slots.sch]
2026-05-24 photo, ods bom
    [teletype-180824-bom.ods]

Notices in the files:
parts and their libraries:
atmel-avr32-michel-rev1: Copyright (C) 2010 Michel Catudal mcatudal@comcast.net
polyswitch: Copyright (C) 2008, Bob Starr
